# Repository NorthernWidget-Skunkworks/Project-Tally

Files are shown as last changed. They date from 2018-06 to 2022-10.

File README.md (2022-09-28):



# Project-Tally
A minimal ultra low power digital event counter, designed to be a counterpart to a traditional data logger to measure and average rapid events like an anemometer reading

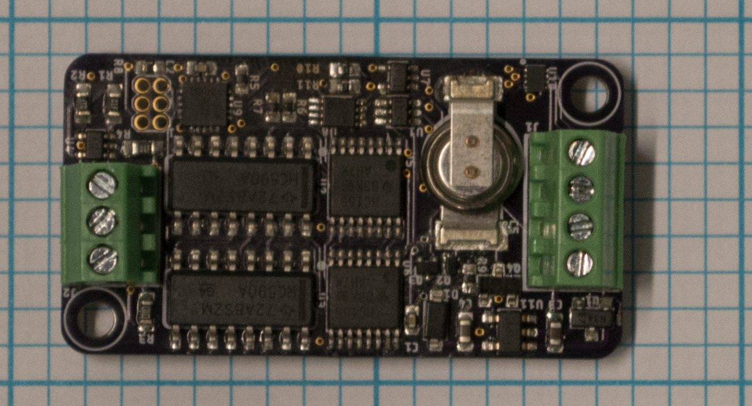
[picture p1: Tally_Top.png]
TallyBoardImage


## Features:
- On board super capacitor (can be self powered between readings/recharge) 
- Extreme low power 
- 3.3/5v capable 
- I2C interface
- Measure up to 65536 (2^16) events before rollover
- Integrated input pullup/pulldown
- Integrated input conditioning (allows for non-binary inputs)

Using jumpers on bottom side of board, can configure input as pullup, pulldown (ultra low power mode), or direct input if driving from another device

### Connectivity:
Device can easily be interfaced to using I2C at either 3.3v or 5v (logic and power). 

A library has been developed for interfacing with Arduino based devices:
[Tally Library](https://github.com/NorthernWidget-Skunkworks/Tally_Library)
### Power Consumption: 

| Mode | Current @ 3.3v | 
| ---- | --- |
| Default | ~4mA |
| Sleep | <100uA |
| Switched | N/A<sup>1</sup> |

<sup>1</sup>When the device is disconnected from the power bus, it draws no external power and runs off the on board super cap. Tested in pull up mode with 100Hz, 50% duty cycle switching input. Ran for 30 minutes, resulting in a consumption of ~ 0.275J of energy = 7.64e-5 Watt Hours -> 15.26 uW avg -> ~ 5uA @ 3v avg. 

#### Maximum input frequency: 

| Mode | Max Freq [kHz] | 
| ---- | --- |
| Pull Up | 16 |
| Pull Down | 10 |
| Direct, Square | 9 |
| Direct, Sine | 22 |
| Direct, Triangle | 22 |

Measured using a function generator with a 2.5v amplitude for push pull tests, and driving an appropriately selected MOSFET for the pull up and pull down variations to act as an analogous switch, once again driven by a function generator. 

---

> ##### ***"Errors using inadequate data are much less than those using no data at all."***
> - **[Charles Babbage](https://en.wikipedia.org/wiki/Charles_Babbage)**

**Concept and design by [Bobby Schulz](https://github.com/bschulz1701) at Northern Widget**

<br>
<br />This work is licensed under a <a rel="license" href="http://creativecommons.org/licenses/by-sa/4.0/">Creative Commons Attribution-ShareAlike 4.0 International License</a>.

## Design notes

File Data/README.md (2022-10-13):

# Wind tunnel test and best fit

`velocity = 0.905 * rps + 0.468`

*Clearly, this breaks down at very slow wind speeds*

`R^2 = 0.959`

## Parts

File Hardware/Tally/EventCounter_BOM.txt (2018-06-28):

Partlist exported from C:/Users/You/Documents/Project-Tally/EventCounter.sch at 6/28/2018 11:52 AM

Qty Value                      Device                     Package                    Parts          Description                                                                                                     DIGIKEY             DISP    MF                  MPN                PROD_ID     VALUE   VALUE_PART
1                              CONN_02SCREW_2.54          1X02_2.54_SCREWTERM        J2             Multi connection point. Often used as Generic Header-pin footprint for 0.1 inch spaced/style header connections ED10561-ND                  OnShore             OSTVN02A150                                      
2                              MOUNTING_HOLE2_NP          2_56                       H1, H2         Genaric Mechanical Mounting Hole                                                                                                                                                                                 
2                              SN74HC165D                 SO16                       U5, U6         SN74HC165 - 8 bit PISO shift register                                                                           296-8250-1-ND               TI                  SN74HC165DR                                      
2                              SN74HC590AD                SO16                       U3, U4         SN74HC590A - 8 bit binary counter with direct clear                                                             296-8340-5-ND               TI                  SN74HC590AD                                      
3                              SN74LVC1G14DCK             DCK_R-PDSO-G5              U1, U9, U10    SN74x1G14 - Single Schmitt Triger Inverter                                                                      296-11608-1-ND              TI                  SN74LVC1G14DCKR                                  
1   0.1uF                      C-EU0.1UFC0603             C0603                      C2             CAPACITOR, European symbol                                                                                      490-6051-1-ND               Murata              GCM188R71E104KA57D                               
4   10M                        R-EU_10MR0603              R0603                      R3, R5, R6, R8 RESISTOR, European symbol                                                                                       RMCF0603FT10M0CT-ND         Stackpole           RMCF0603FT10M0                         10M       
1   10k                        R-EU_10KR0603              R0603                      R1             RESISTOR, European symbol                                                                                       P10.0KHCT-ND                Panasonic           ERJ-3EKF1002V                          10k       
2   1uF                        C-EU1UFC0603               C0603                      C1, C3         CAPACITOR, European symbol                                                                                      1276-6524-1-ND              Samsung             1276-6524-1-ND                                   
1   2N7002                     MOSFET-NCH-2N7002PW        SOT323                     Q1             N-channel MOSFETs                                                                                               2N7002W-FDICT-ND            Diodes Incorporated 2N7002W-7-F        TRANS-11151 2N7002            
3   3.3M                       R-EU_3.3MR0603             R0603                      R2, R4, R7     RESISTOR, European symbol                                                                                       RMCF0603FT3M30CT-ND         Stackpole           RMCF0603FT3M30                         3.3M      
1   CONN_42.54_SCREW           CONN_42.54_SCREW           1X04_SCREW                 J1             Genaric 4 pin connector                                                                                         ED10563-ND                  On Shore            OSTVN04A150                                      
1   DMG3404                    MOSFET-NCH-DMG3404L        SOT23-3                    Q3             N-channel MOSFETs                                                                                               DMG3404L-7DICT-ND           Diodes Incorporated DMG3404L-7                     DMG3404           
1   JUMPER-SMT_2_NC_PASTE_SILK JUMPER-SMT_2_NC_PASTE_SILK SMT-JUMPER_2_NC_PASTE_SILK JP1            Normally closed solder jumper                                                                                                                                                                                    
3   MCP6041                    MCP6041                    SOT23-5                    U2, U7, U8     MCP6041 - Low Power Rail to Rail Op-Amp                                                                         MCP6041T-I/OTCT-ND  MCP6041 Microchip           MCP6041T-I/OT                                    
1   MIC842H                    MIC842H                    DCK_R-PDSO-G5              U$1            Comparator with internal voltage referance (1.24V), 5V and 3.3V compatable, 20mA output current                 576-2926-1-ND               Microchip           MIC842HYC5-TR

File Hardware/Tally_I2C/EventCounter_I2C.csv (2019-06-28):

Qty | Value | Device | Package | Parts | Description | DIGIKEY | MF | MOUSER | MPN | VALUE | VALUE_PART
1 |  | DIODESOD-123 | SOD-123 | D1 | Genaric Diode | BAT43W-FDICT-ND | Diodes Incorporated |  | BAT43W-7-F
2 |  | MOUNTING_HOLE2_NP | 2_56 | H1, H2 | Genaric Mechanical Mounting Hole
1 |  | SN74AUP2G14SC70 | DCK_R-PDSO-G6 | U1 | SN74x2G14 - Dual Schmitt Triger Inverter | 296-27361-1-ND | TI |  | SN74AUP2G14DCKR
2 |  | SN74HC165PW | TSSOP16 | U5, U6 | SN74HC165 - 8 bit PISO shift register | 296-8253-1-ND | TI |  | SN74HC165PWR
2 |  | SN74HC590AD | SO16 | U2, U3 | SN74HC590A - 8 bit binary counter with direct clear | 296-8340-5-ND | TI |  | SN74HC590AD
2 | 0.1uF | C-EU0.1UFC0402 | C0402 | C1, C2 | CAPACITOR, European symbol | 490-4759-1-ND | Murata |  | GCM155R71C104KA55D
1 | 100k | R-EU_100KR0603 | R0603 | R3 | RESISTOR, European symbol | RC0402FR-071ML | Yageo |  | RC0603FR-07100KL |  | 100k
3 | 10M | R-EU_10MR0603 | R0603 | R1, R2, R4 | RESISTOR, European symbol | RMCF0603FT10M0CT-ND | Stackpole |  | RMCF0603FT10M0 |  | 10M
5 | 10k | R-EU_10KR0402 | R0402 | R5, R6, R7, R8, R11 | RESISTOR, European symbol | 311-10KJRCT-ND | Yageo |  | RC0402JR-0710KL |  | 10k
2 | 1M | R-EU_1MR0402 | R0402 | R9, R10 | RESISTOR, European symbol | 311-1.00MLRCT-ND | Yageo |  | RC0402FR-071ML |  | 1M
2 | 1uF | C-EU1UFC0603 | C0603 | C3, C4 | CAPACITOR, European symbol | 490-10479-1-ND | Murata |  | GRM188R61C105KA12D
1 | 220mF | CPOL-EUHL | HL | C5 | POLARIZED CAPACITOR, European symbol | 604-1020-1-ND | Elna |  | DSK-3R3H224U-HL
1 | ATTINY441/841VQFN | ATTINY441/841VQFN | VQFN-20 | U9 | ATtiny841/441 8 bit AVR Microcontroller | ATTINY841-MMHRCT-ND | Atmel |  | ATTINY841-MMHR
1 | AVRISP1.27MM | AVRISP1.27MM | 2X3_1.27 | ISP1 | AVR ISP HEADER
1 | CONN_32.54_SCREW | CONN_32.54_SCREW | 1X03_SCREW | J2 | Genaric 3 terminal header | ED10562-ND | On Shore |  | OSTVN03A150
1 | CONN_42.54_SCREW | CONN_42.54_SCREW | 1X04_SCREW | J1 | Genaric 4 terminal header | ED10563-ND | On Shore |  | OSTVN04A150
1 | DMG3404 | MOSFET-NCH-DMG3404L | SOT23-3 | Q1 | N-channel MOSFETs | DMG3404L-7DICT-ND | Diodes Incorporated |  | DMG3404L-7 | DMG3404
1 | JUMPER-SMT_3_1-NC_PASTE_SILK | JUMPER-SMT_3_1-NC_PASTE_SILK | SMT-JUMPER_3_1-NC_PASTE_SILK | JP0 | Normally closed solder jumper (1 of 2 connections)
1 | MOSFET-NCH-RE1C002UN | MOSFET-NCH-RE1C002UN | SC-89 | Q3 | N-channel MOSFETs | RE1C002UNTCLCT-ND | Rohm |  | RE1C002UNTCL
1 | MOSFET_PCH-NX2301P | MOSFET_PCH-NX2301P | SOT23-3 | Q4 | P-channel MOSFETs | 1727-1148-1-ND | Nexperia |  | NX2301P | 215
1 | MOSFET_PCH-RZM001P02 | MOSFET_PCH-RZM001P02 | SOT723 | Q2 | P-channel MOSFETs | RZM001P02T2LCT-ND | Rohm |  | RZM001P02T2L
1 | SN74AUP1G34SC70 | SN74AUP1G34SC70 | DCK_R-PDSO-G5 | U7 | SN74AUP1G34 - Logic Buffer | 296-17230-1-ND | TI |  | SN74LVC1G34DCKR
1 | SN74AUP3G34DCU | SN74AUP3G34DCU | DCU_(R-PDSO-G8) | U8 | SN74AUP3G34 - Logic Buffer | 296-25595-1-ND | TI |  | SN74AUP3G34DCUR
1 | TLV3691DCK | TLV3691DCK | DCK_R-PDSO-G5 | U4 | TLV3691 - Nanopower Analog Comparator | 296-37910-1-ND | TI |  | TLV3691IDCKR
1 | TPS7A0533DBV | TPS7A0533DBV | SOT23-5 | U11 | TPS7A05* - Ultra Low Power Low Dropout Linear Regulator | 296-50256-1-ND | TI | 595-TPS7A0533PDBVR | TPS7A0533PDBVR
1 | TXS0102DQM | TXS0102DQM | DQM_R-PX2SON-N8 | U10 | TXS0102 - 2 Channel Bidirectional Voltage Level Translator | 296-28435-1-ND | TI |  | TXS0102DQMR

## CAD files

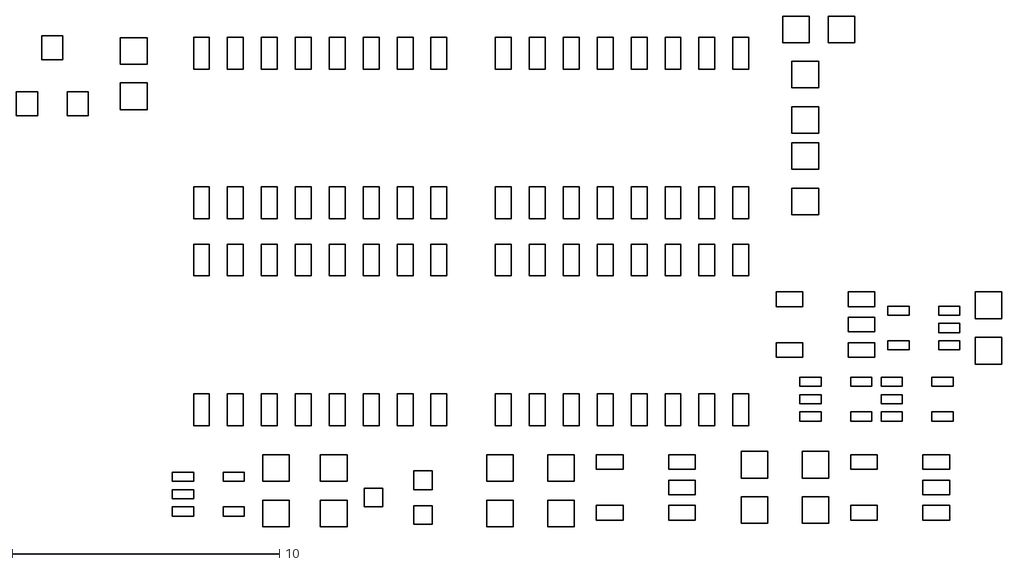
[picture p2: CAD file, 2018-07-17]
Hardware/Tally/Stencil.dxf
36.9 x 19.1

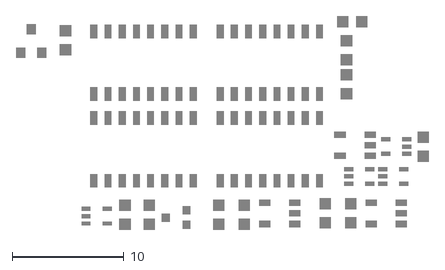
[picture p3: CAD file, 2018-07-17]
Hardware/Tally/EventCounter.dxf
36.9 x 19.1

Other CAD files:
3Dprint/StencilMount_Tally_I2C.SLDPRT
Hardware/Tally/EventCounter-bcream.dxf
Hardware/Tally/EventCounter-tcream.dxf
3Dprint/StencilMount_Tally_I2C.STL

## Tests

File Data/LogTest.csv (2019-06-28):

Freq, Measured (Max) [Hz] | Freq, Measured (Min) [Hz] | Freq, Measured (Avg) [Hz] | Freq, Tally [Hz]
1.659 | 1.456 | 1.549 | 1.55
4.114 | 3.723 | 3.906 | 3.9
5.39 | 4.994 | 5.236 | 5.233
0.822 | 0.639 | 0.721 | 0.7166

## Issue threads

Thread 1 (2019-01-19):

Fix orientation on switched power adapter

bschulz1701, 2019-01-19:
Fix orientation of pins so they line up with Tally correctly

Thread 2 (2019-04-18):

Digital Pull-up/down resistors

bschulz1701, 2019-04-18:
### Upgrade (Only relevant on I2C version)
Make the pull up/pull down resistors on the pulse input be able to be controlled via the micro over I2C

### Implementation
Use a mosfet to connect or disconnect the appropriate resistor, use a digital latch in order to drive the gate of the mosfet so that the fet will remain in the set position even when the micro is powered down. May also need to add a buffer in series with latch in order to prevent reverse current in shutdown mode?

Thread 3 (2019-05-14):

Add Jumper for Capacitor

bschulz1701, 2019-05-14:
Potentially add a jumper to disconnect the capacitor when not used (by an always on system) in order to reduce current spikes (due to charging) and to simplify power analysis

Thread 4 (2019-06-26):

Add mount points for Grove connector

bschulz1701, 2019-06-26:
Add connection pads for Grove connector underneath the I2C screw terminal

Consider adding Qwiic connection as well depending on size and ease of addition

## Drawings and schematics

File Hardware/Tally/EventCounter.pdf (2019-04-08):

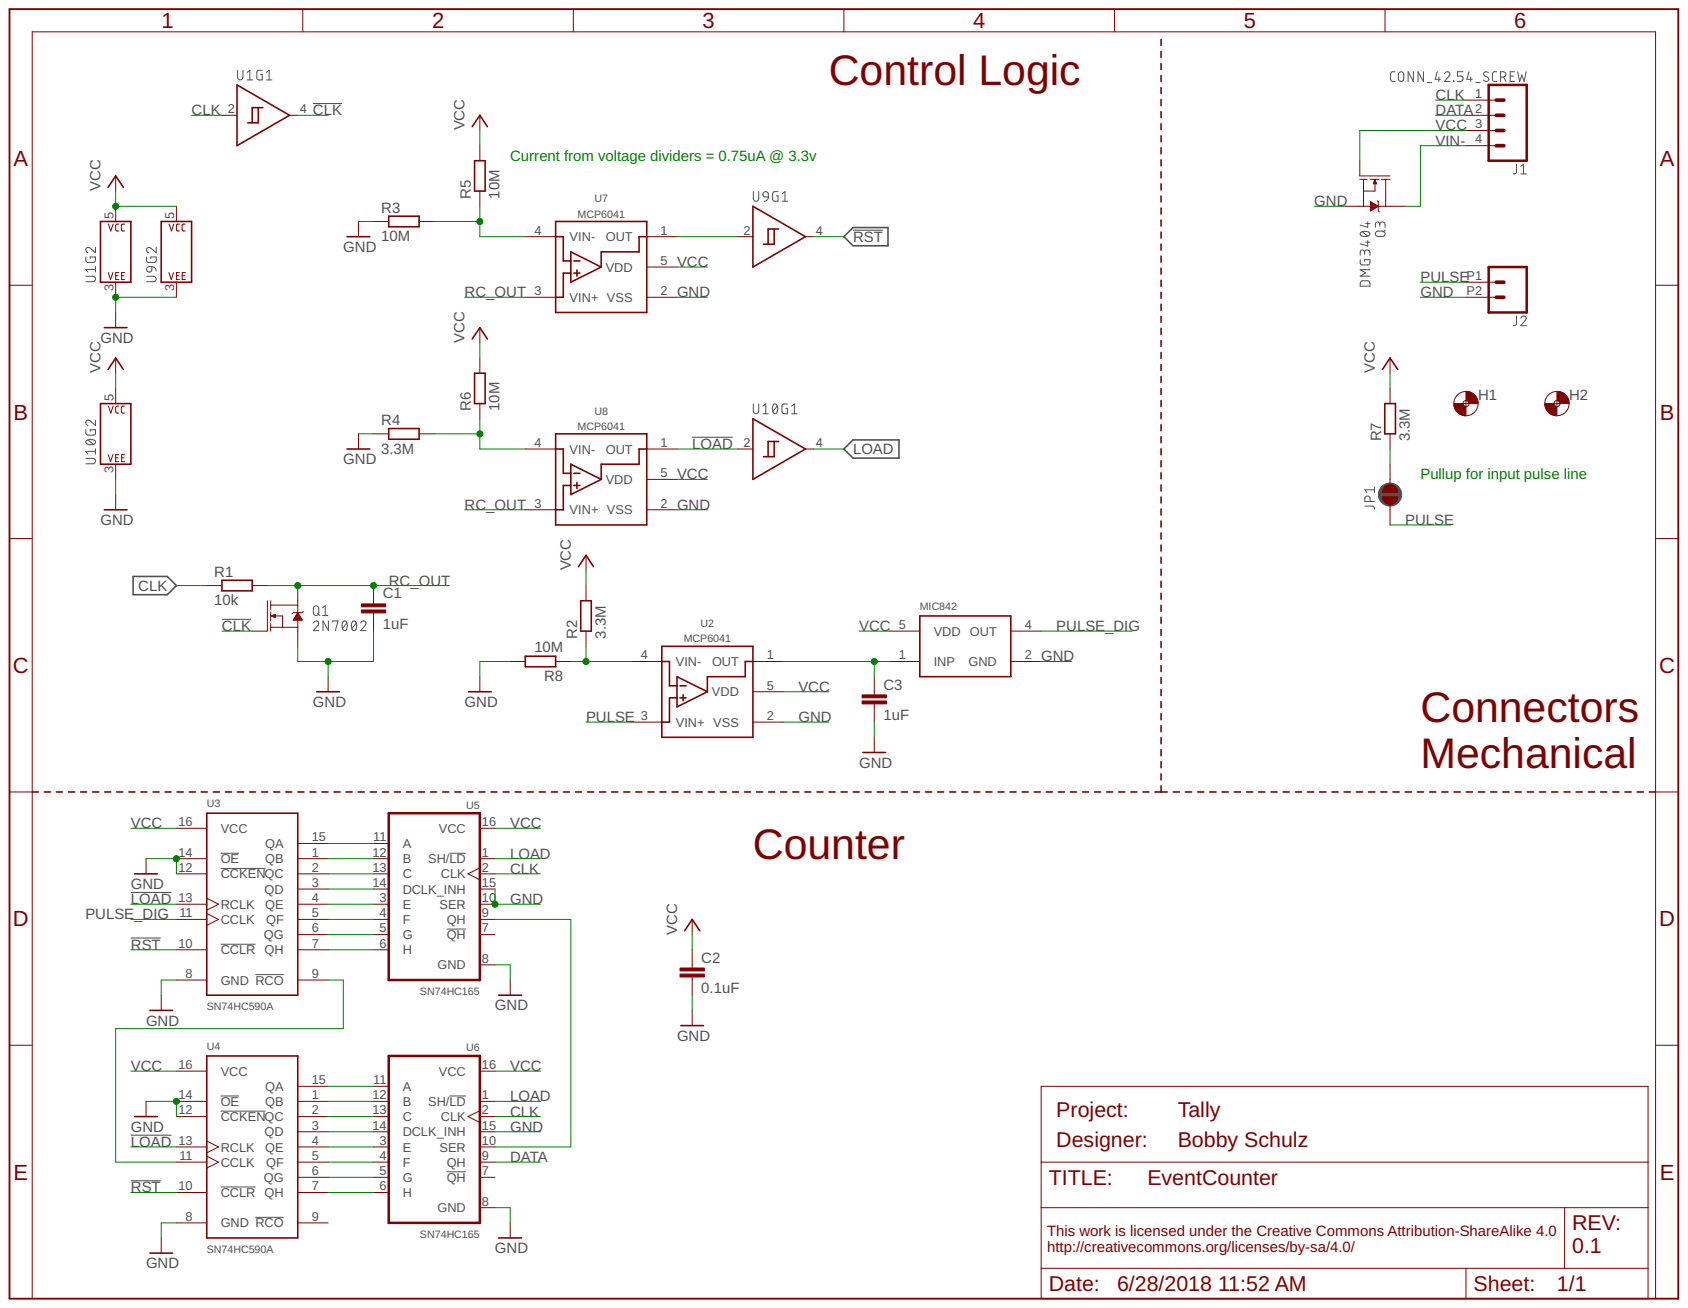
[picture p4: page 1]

Current from voltage dividers = 0.75uA @ 3.3v

Pullup for input pulse line

This work is licensed under the Creative Commons Attribution-ShareAlike 4.0 http://creativecommons.org/licenses/by-sa/4.0/ | REV: 0.1

Date: 6/28/2018 11:52 AM | Sheet: 1/1

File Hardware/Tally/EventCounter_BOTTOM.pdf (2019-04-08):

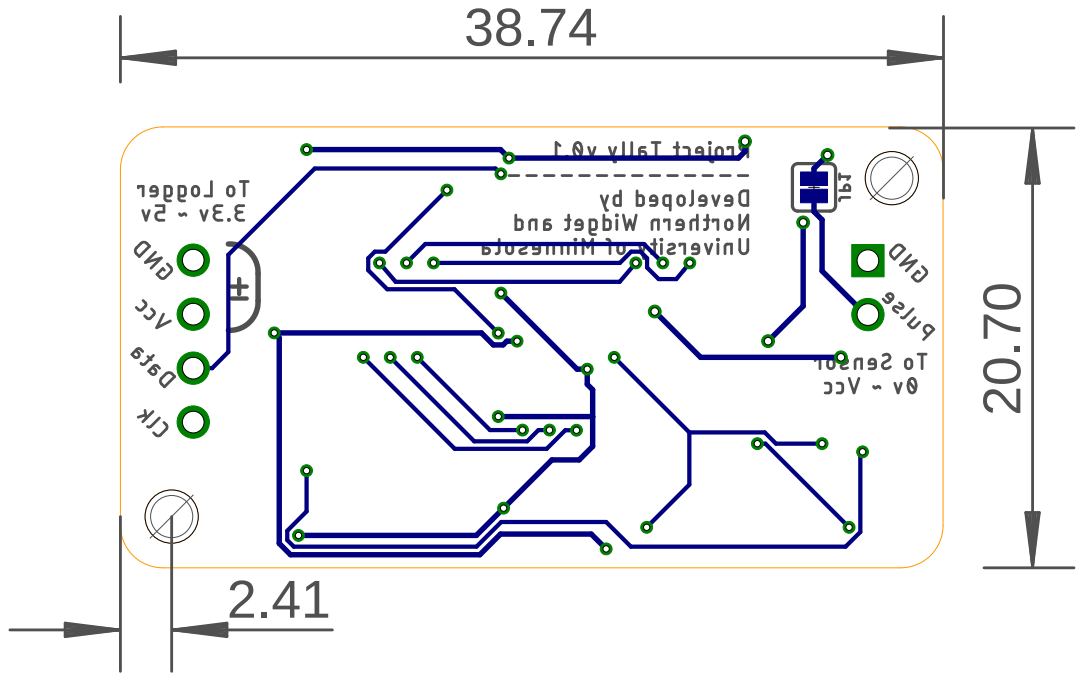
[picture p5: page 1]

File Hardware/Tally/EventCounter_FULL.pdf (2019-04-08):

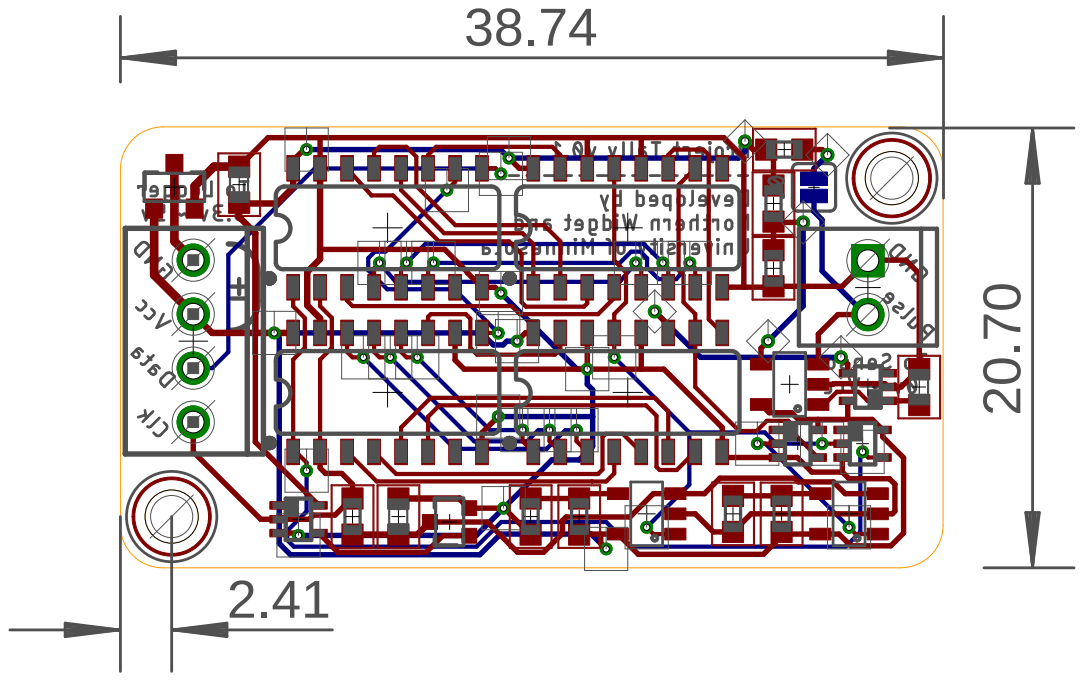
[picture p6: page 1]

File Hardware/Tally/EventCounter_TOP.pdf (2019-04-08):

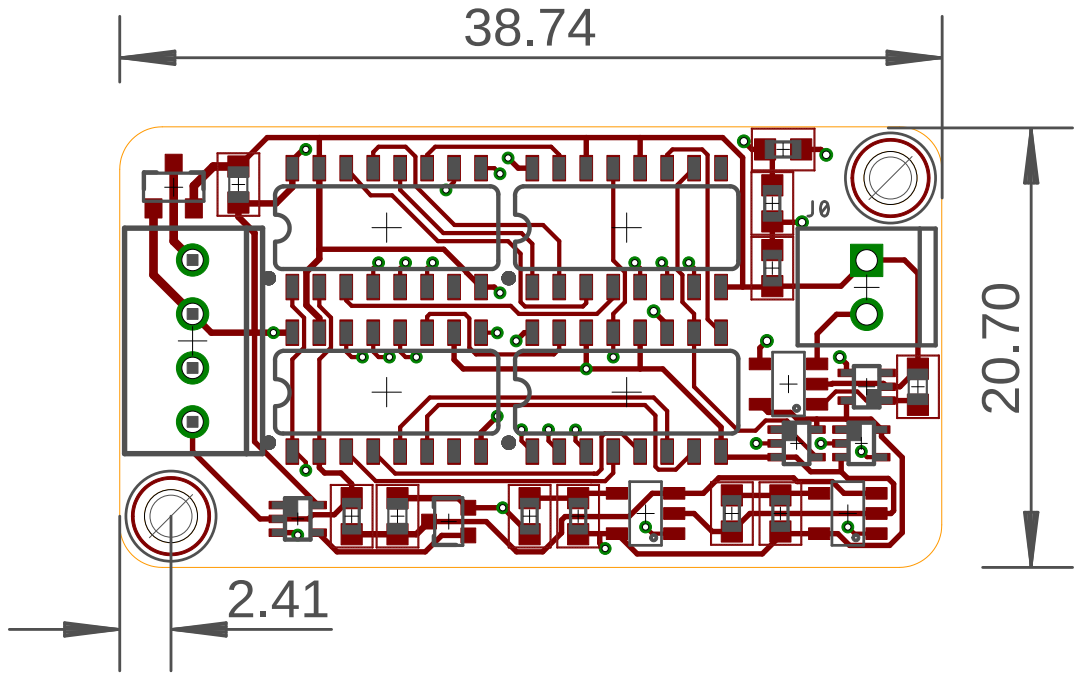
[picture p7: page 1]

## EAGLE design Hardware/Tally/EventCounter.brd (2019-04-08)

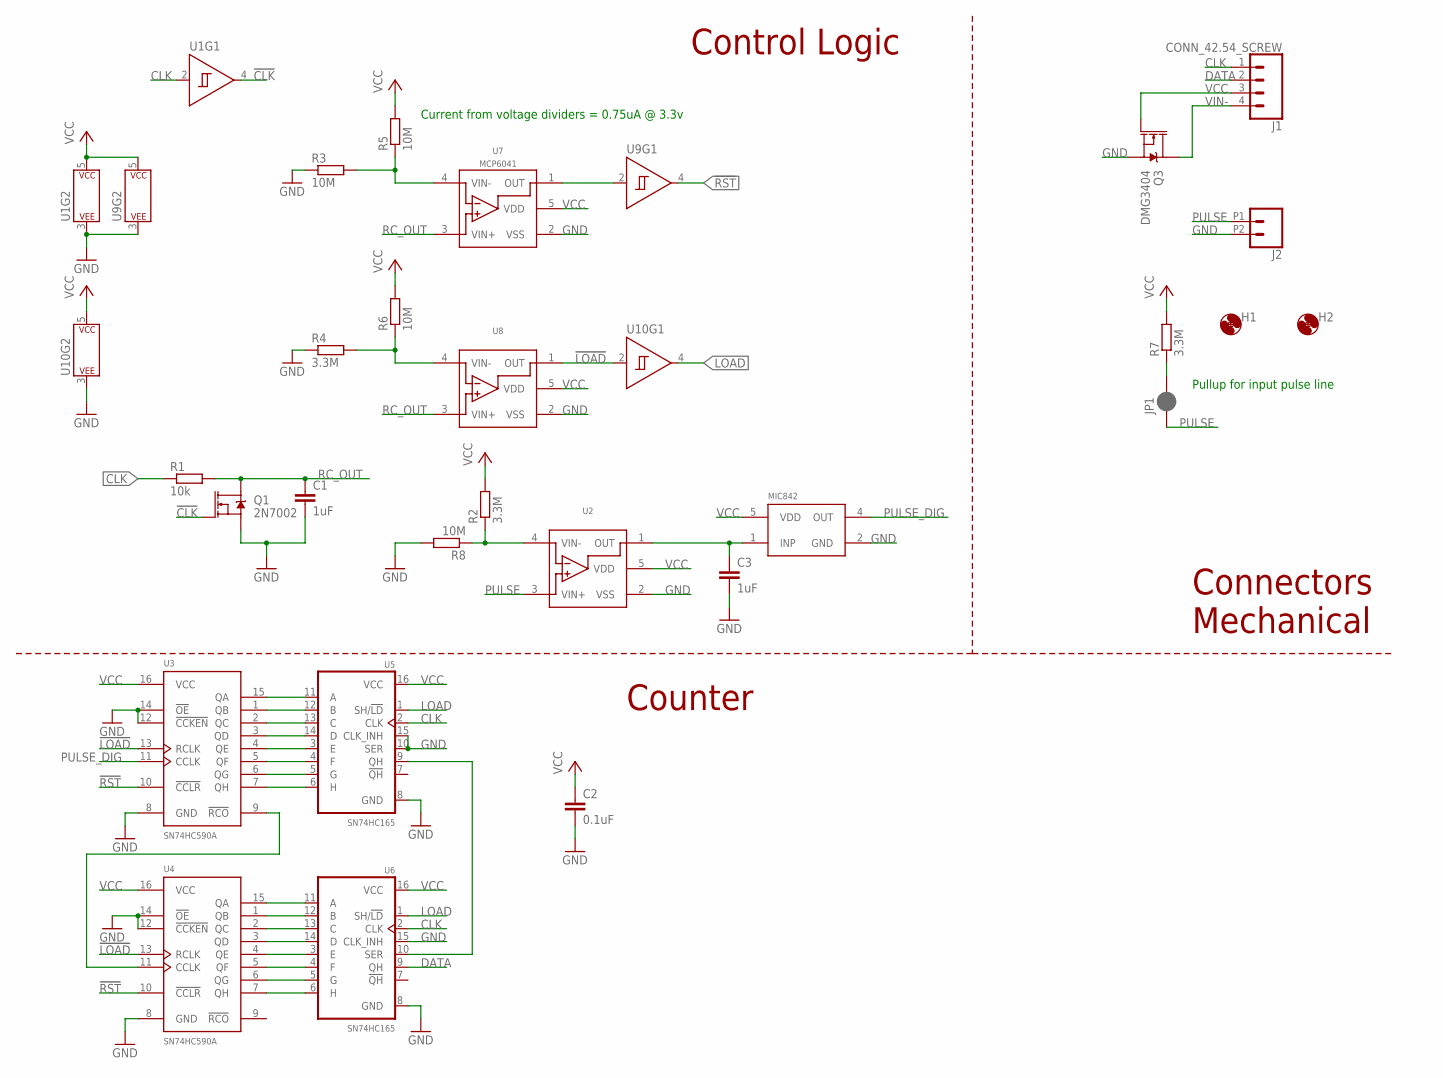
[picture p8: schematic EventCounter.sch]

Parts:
C1, C3: 1uF; C0603
C2: 0.1uF; C0603
H1, H2: MOUNTING_HOLE2_NP; 2_56
J1: CONN_42.54_SCREW; 1X04_SCREW
J2: CONN_02SCREW_2.54; 1X02_2.54_SCREWTERM
JP1: JUMPER-SMT_2_NC_PASTE_SILK; SMT-JUMPER_2_NC_PASTE_SILK
Q1: 2N7002; SOT323
Q3: DMG3404; SOT23-3
R1: 10k; R0603
R2, R4, R7: 3.3M; R0603
R3, R5, R6, R8: 10M; R0603
U1, U9, U10: SN74LVC1G14DCK; DCK_R-PDSO-G5
U2, U7, U8: MCP6041; SOT23-5
U3, U4: SN74HC590AD; SO16
U5, U6: SN74HC165D; SO16
U$1: MIC842H; DCK_R-PDSO-G5

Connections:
!CLK: Q1.1 (G), U1.4 (Y)
!LOAD: U3.13 (RCLK), U4.13 (RCLK), U8.1 (OUT), U10.2 (A)
!RST: U3.10 (!CCLR), U4.10 (!CCLR), U9.4 (Y)
CLK: J1.1, R1.1, U1.2 (A), U5.2 (CLK), U6.2 (CLK)
DATA: J1.2, U6.9 (QH)
GND: C1.2, C2.2, C3.2, J2.P2 (2), Q1.2 (S), Q3.2 (S), R3.1, R4.1, R8.2, U1.3 (P$V-), U2.2 (VSS), U3.8 (GND), U3.12 (!CCKEN), U3.14 (!OE), U4.8 (GND), U4.12 (!CCKEN), U4.14 (!OE), U5.8 (GND), U5.10 (SER), U5.15 (CLK_INH), U6.8 (GND), U6.15 (CLK_INH), U7.2 (VSS), U8.2 (VSS), U9.3 (P$V-), U10.3 (P$V-), U$1.2 (GND)
LOAD: U5.1 (SH/!LD), U6.1 (SH/!LD), U10.4 (Y)
unnamed: U4.15 (QA), U6.11 (A)
unnamed: U4.1 (QB), U6.12 (B)
unnamed: U4.2 (QC), U6.13 (C)
unnamed: U4.3 (QD), U6.14 (D)
unnamed: U4.4 (QE), U6.3 (E)
unnamed: U4.5 (QF), U6.4 (F)
unnamed: U4.6 (QG), U6.5 (G)
unnamed: U4.7 (QH), U6.6 (H)
unnamed: U3.7 (QH), U5.6 (H)
unnamed: U3.6 (QG), U5.5 (G)
unnamed: U3.5 (QF), U5.4 (F)
unnamed: U3.4 (QE), U5.3 (E)
unnamed: U3.3 (QD), U5.14 (D)
unnamed: U3.2 (QC), U5.13 (C)
unnamed: U3.1 (QB), U5.12 (B)
unnamed: U3.15 (QA), U5.11 (A)
unnamed: U5.9 (QH), U6.10 (SER)
unnamed: U3.9 (!RCO), U4.11 (CCLK)
unnamed: R2.1, R8.1, U2.4 (VIN-)
unnamed: JP1.2, R7.1
unnamed: R4.2, R6.1, U8.4 (VIN-)
unnamed: C3.1, U2.1 (OUT), U$1.1 (INP)
unnamed: R3.2, R5.1, U7.4 (VIN-)
PULSE: J2.P1 (1), JP1.1, U2.3 (VIN+)
PULSE_DIG: U3.11 (CCLK), U$1.4 (OUT)
RC_OUT: C1.1, Q1.3 (D), R1.2, U7.3 (VIN+), U8.3 (VIN+)
RST: U7.1 (OUT), U9.2 (A)
VCC: C2.1, J1.3, Q3.1 (G), R2.2, R5.2, R6.2, R7.2, U1.5 (P$V+), U2.5 (VDD), U3.16 (VCC), U4.16 (VCC), U5.16 (VCC), U6.16 (VCC), U7.5 (VDD), U8.5 (VDD), U9.5 (P$V+), U10.5 (P$V+), U$1.5 (VDD)
VIN-: J1.4, Q3.3 (D)

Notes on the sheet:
Pullup for input pulse line
Counter
Control Logic
Connectors Mechanical
Current from voltage dividers = 0.75uA @ 3.3v

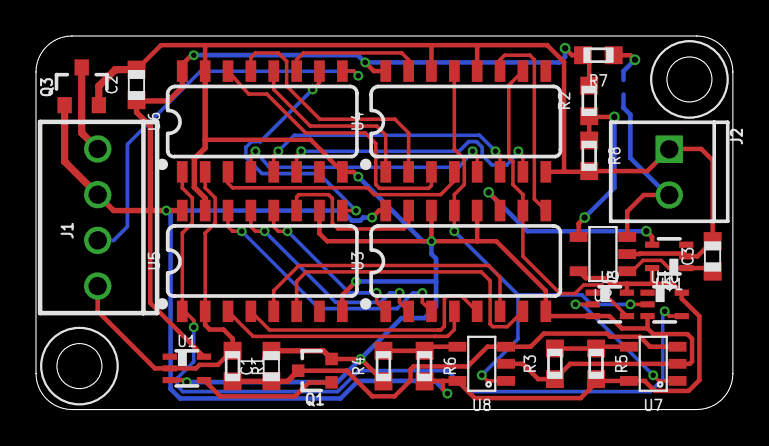
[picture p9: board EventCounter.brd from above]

Board: 2 copper layers, 38.7 x 20.8 mm, 29 parts (1 on the bottom side), 36 nets.

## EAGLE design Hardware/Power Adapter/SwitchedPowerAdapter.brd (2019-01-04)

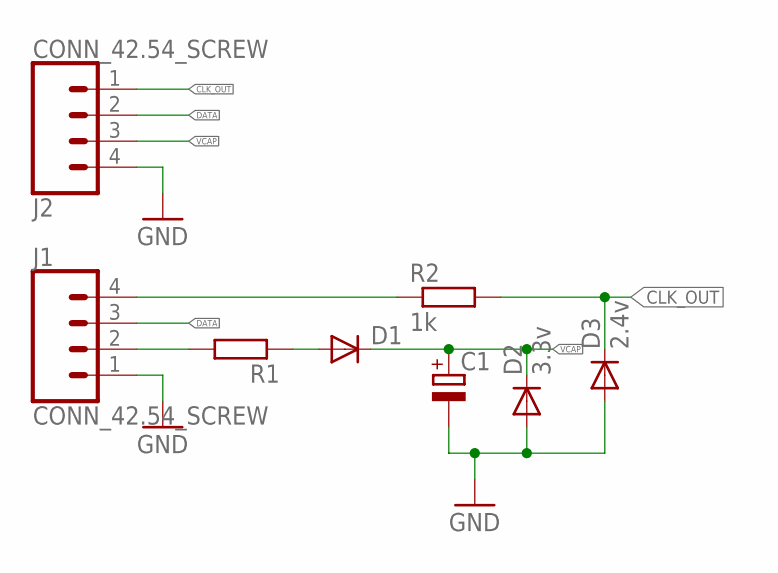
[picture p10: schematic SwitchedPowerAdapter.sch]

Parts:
C1: CPOL-EUHL; HL
D1: DIODEDO-214AC; DO214AC; MPN S1A; DIGIKEY S1AFSCT-ND
D2: 3.3v; SOD-123; MPN MMSZ4683-HE3-08; DIGIKEY MMSZ4683-HE3-08GICT-ND
D3: 2.4v; SOD-123
J1, J2: CONN_42.54_SCREW; 1X04_SCREW
R1: R-EU_R2512; R2512
R2: 1k; R0402

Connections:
CLK: J1.4, R2.1
CLK_OUT: D3.CAT (C), J2.1, R2.2
DATA: J1.3, J2.2
GND: C1.-, D2.ANODE (A), D3.ANODE (A), J1.1, J2.4
unnamed: J1.2, R1.2
unnamed: D1.A, R1.1
VCAP: C1.+, D1.C, D2.CAT (C), J2.3

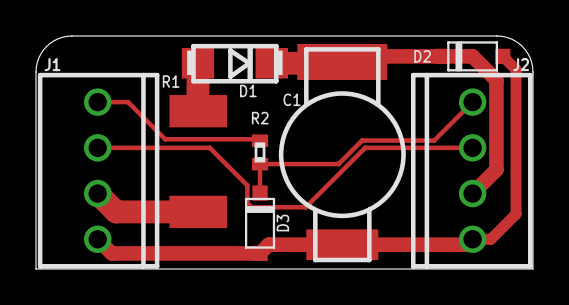
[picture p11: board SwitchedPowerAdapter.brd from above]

Board: 2 copper layers, 27.6 x 12.9 mm, 8 parts (0 on the bottom side), 7 nets.

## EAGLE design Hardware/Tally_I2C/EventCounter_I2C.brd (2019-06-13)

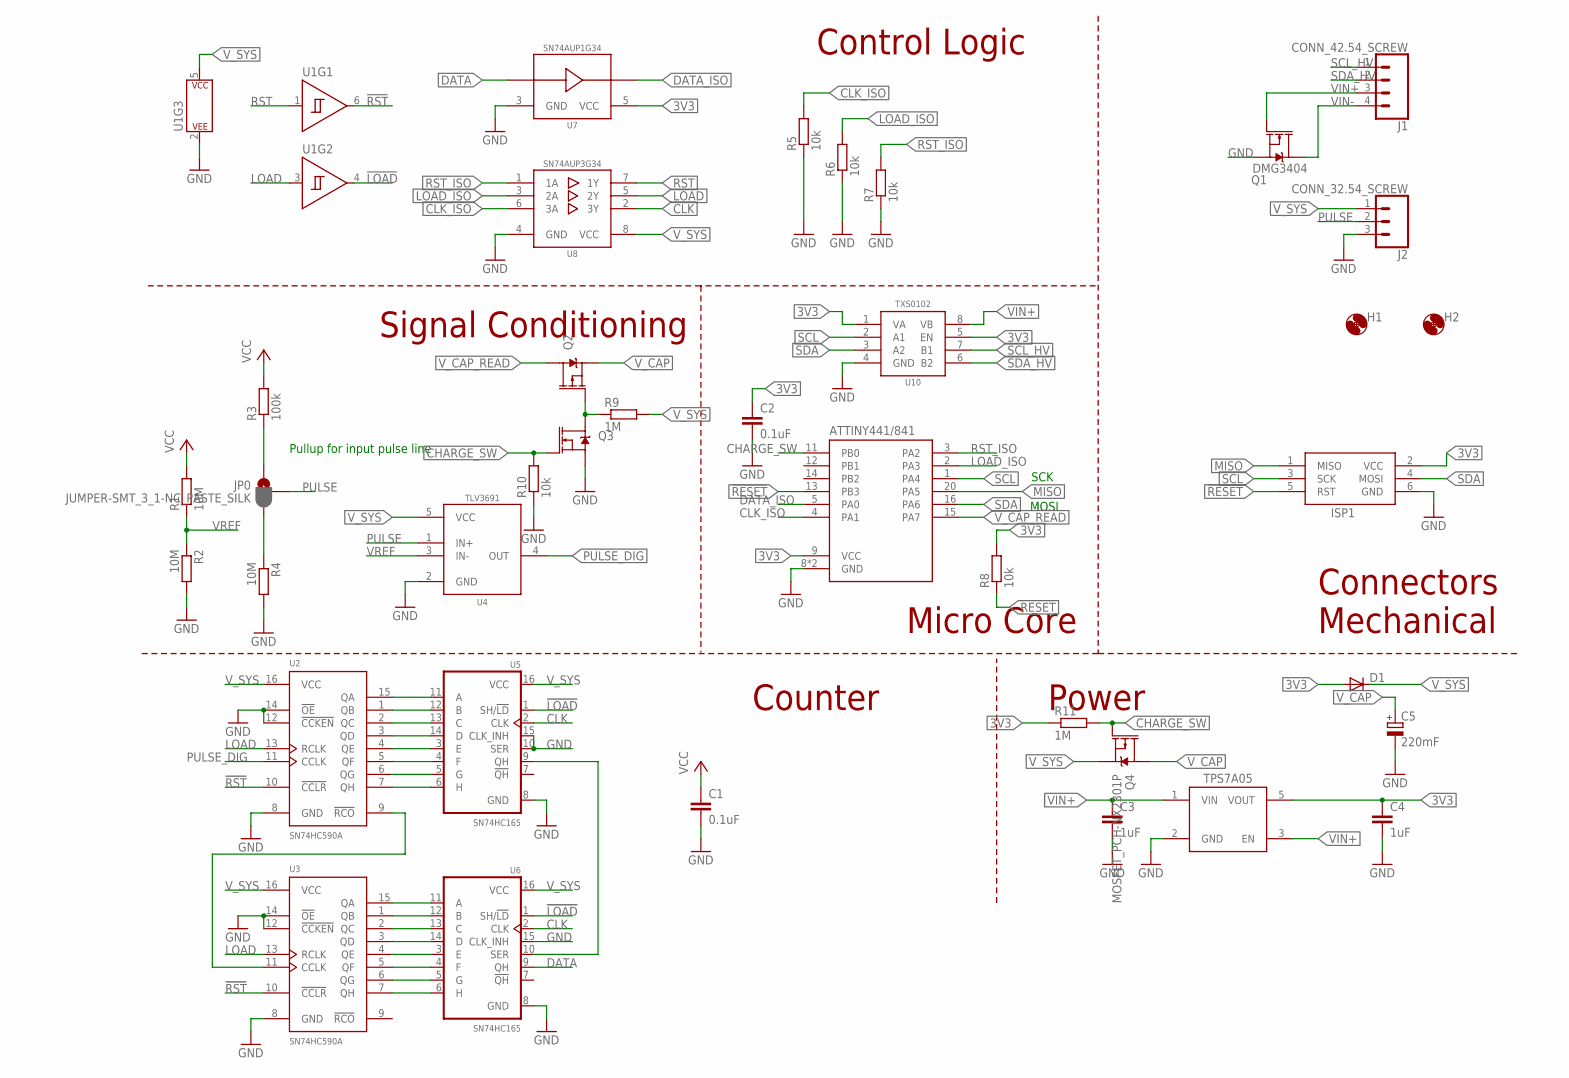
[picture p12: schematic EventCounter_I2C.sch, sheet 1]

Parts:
C1, C2: 0.1uF; C0402
C3, C4: 1uF; C0603
C5: 220mF; HL; MPN DSK-3R3H224U-HL; DIGIKEY 604-1020-1-ND
D1: DIODESOD-123; SOD-123; MPN BAT43W-7-F; DIGIKEY BAT43W-FDICT-ND
H1, H2: MOUNTING_HOLE2_NP; 2_56
ISP1: AVRISP1.27MM; 2X3_1.27
J1: CONN_42.54_SCREW; 1X04_SCREW
J2: CONN_32.54_SCREW; 1X03_SCREW
JP0: JUMPER-SMT_3_1-NC_PASTE_SILK; SMT-JUMPER_3_1-NC_PASTE_SILK
Q1: DMG3404; SOT23-3
Q2: MOSFET_PCH-RZM001P02; SOT723
Q3: MOSFET-NCH-RE1C002UN; SC-89
Q4: MOSFET_PCH-NX2301P; SOT23-3
R1, R2, R4: 10M; R0603
R3: 100k; R0603
R5, R6, R7, R8, R10: 10k; R0402
R9, R11: 1M; R0402
U1: SN74AUP2G14SC70; DCK_R-PDSO-G6
U2, U3: SN74HC590AD; SO16
U4: TLV3691DCK; DCK_R-PDSO-G5
U5, U6: SN74HC165PW; TSSOP16
U7: SN74AUP1G34SC70; DCK_R-PDSO-G5
U8: SN74AUP3G34DCU; DCU_(R-PDSO-G8)
U9: ATTINY441/841VQFN; VQFN-20
U10: TXS0102DQM; DQM_R-PX2SON-N8
U11: TPS7A0533DBV; SOT23-5

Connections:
3V3: C2.1, C4.1, D1.ANODE (A), ISP1.2 (VCC), R8.2, R11.1, U7.5 (VCC), U9.9 (VCC), U10.1 (VA), U10.5 (EN), U11.5 (VOUT)
!LOAD: U1.4 (Y), U5.1 (SH/!LD), U6.1 (SH/!LD)
!RESET: ISP1.5 (RST), R8.1, U9.13 (PB3)
!RST: U1.6 (Y), U2.10 (!CCLR), U3.10 (!CCLR)
CHARGE_SW: Q3.1 (G), Q4.1 (G), R10.2, R11.2, U9.11 (PB0)
CLK: U5.2 (CLK), U6.2 (CLK), U8.2 (3Y)
CLK_ISO: R5.2, U8.6 (3A), U9.4 (PA1)
DATA: U6.9 (QH), U7.2 (A)
DATA_ISO: U7.4 (Y), U9.5 (PA0)
GND: C1.2, C2.2, C3.2, C4.2, C5.-, ISP1.6 (GND), J2.3, Q1.2 (S), Q3.2 (S), R2.2, R4.2, R5.1, R6.1, R7.1, R10.1, U1.2 (P$V-), U2.8 (GND), U2.12 (!CCKEN), U2.14 (!OE), U3.8 (GND), U3.12 (!CCKEN), U3.14 (!OE), U4.2 (GND), U5.8 (GND), U5.10 (SER), U5.15 (CLK_INH), U6.8 (GND), U6.15 (CLK_INH), U7.3 (GND), U8.4 (GND), U9.8 (GND), U9.EP (GND), U10.4 (GND), U11.2 (GND)
LOAD: U1.3 (A), U2.13 (RCLK), U3.13 (RCLK), U8.5 (2Y)
LOAD_ISO: R6.2, U8.3 (2A), U9.2 (PA3)
MISO: ISP1.1 (MISO), U9.20 (PA5)
unnamed: U3.15 (QA), U6.11 (A)
unnamed: U3.1 (QB), U6.12 (B)
unnamed: U3.2 (QC), U6.13 (C)
unnamed: U3.3 (QD), U6.14 (D)
unnamed: U3.4 (QE), U6.3 (E)
unnamed: U3.5 (QF), U6.4 (F)
unnamed: U3.6 (QG), U6.5 (G)
unnamed: U3.7 (QH), U6.6 (H)
unnamed: U2.7 (QH), U5.6 (H)
unnamed: U2.6 (QG), U5.5 (G)
unnamed: U2.5 (QF), U5.4 (F)
unnamed: U2.4 (QE), U5.3 (E)
unnamed: U2.3 (QD), U5.14 (D)
unnamed: U2.2 (QC), U5.13 (C)
unnamed: U2.1 (QB), U5.12 (B)
unnamed: U2.15 (QA), U5.11 (A)
unnamed: U5.9 (QH), U6.10 (SER)
unnamed: U2.9 (!RCO), U3.11 (CCLK)
unnamed: JP0.3, R4.1
unnamed: JP0.1, R3.1
unnamed: Q2.1 (G), Q3.3 (D), R9.1
PULSE: J2.2, JP0.2, U4.1 (IN+)
PULSE_DIG: U2.11 (CCLK), U4.4 (OUT)
RST: U1.1 (A), U8.7 (1Y)
RST_ISO: R7.2, U8.1 (1A), U9.3 (PA2)
SCL: ISP1.3 (SCK), U9.1 (PA4), U10.2 (A1)
SCL_HV: J1.1, U10.7 (B1)
SDA: ISP1.4 (MOSI), U9.16 (PA6), U10.3 (A2)
SDA_HV: J1.2, U10.6 (B2)
VIN+: C3.1, J1.3, Q1.1 (G), U10.8 (VB), U11.1 (VIN), U11.3 (EN)
VIN-: J1.4, Q1.3 (D)
VREF: R1.1, R2.1, U4.3 (IN-)
V_CAP: C5.+, Q2.2 (S), Q4.3 (D)
V_CAP_READ: Q2.3 (D), U9.15 (PA7)
V_SYS: C1.1, D1.CAT (C), J2.1, Q4.2 (S), R1.2, R3.2, R9.2, U1.5 (P$V+), U2.16 (VCC), U3.16 (VCC), U4.5 (VCC), U5.16 (VCC), U6.16 (VCC), U8.8 (VCC)

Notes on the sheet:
Pullup for input pulse line
Counter
Control Logic
Connectors Mechanical
MOSI
SCK
Power
Micro Core
Signal Conditioning

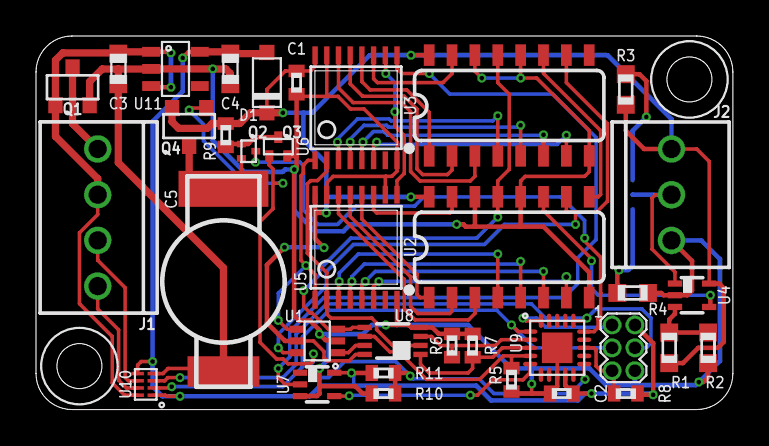
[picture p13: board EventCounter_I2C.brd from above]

Board: 2 copper layers, 38.7 x 20.8 mm, 38 parts (1 on the bottom side), 48 nets.

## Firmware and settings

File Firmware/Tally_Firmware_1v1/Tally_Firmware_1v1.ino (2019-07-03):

/******************************************************************************
Tally_Firmware_1v1.ino
Driver for Tally event counter
Bobby Schulz @ Northern Widget LLC
5/16/2019
https://github.com/NorthernWidget-Skunkworks/Project-Tally

This firmware is to be run on the I2C capable Tally v1.1 in order to allow for interface, control, and data collection 

Firmware Version: 0.2.0

"On two occasions I have been asked, 'Pray, Mr. Babbage, if you put into the machine wrong figures, will the right answers come out?' 
I am not able rightly to apprehend the kind of confusion of ideas that could provoke such a question."
-Charles Babbage

Distributed as-is; no warranty is given.
******************************************************************************/

#include <avr/sleep.h>
#include <avr/power.h>
#include <avr/interrupt.h>
#include "WireS.h"
#define DATA_PIN 10
#define CLK_PIN 9
#define RST_PIN 8
#define LOAD_PIN 7
#define CHARGE_SW 0
#define V_CAP_READ A7

#define CHIP_ID_CALL 0xD0
#define CHIP_ID 0xB0
#define FIRMWARE_NUM 2

uint8_t ADR = 0x33; //DUMMY! FIX! and make changable

// volatile bool GenCall = false; //Flag for generic address call over I2C //FIX! add generalizable address

uint8_t Config = 0; //Global config value
uint8_t Reg[5] = {0}; //Initialize registers
const uint8_t RegLen = sizeof(Reg); //Number of registers in Reg
bool Sample = false; //Flag to get a new sample value
bool Reset = false; //Reset flag
bool Clear = false; //Clear registers
bool Peek = false; //Clear values on read by default
bool Sleep = false; //Do not sleep by default
bool ReadCap = false; //Read float voltage of capacitor 
bool NoCap = false; //Disconnect capacitor, this will be reset on POR

volatile bool StopFlag = false; //Used to indicate a stop condition 
volatile uint8_t RegID = 0; //Used to denote which register will be read from
volatile bool RepeatedStart = false; //Used to show if the start was repeated or not

const unsigned long WAIT_TIME = 100; //Genric wait cycle after read operation, keep device alive for repeated requests

void setup() {
	pinMode(DATA_PIN, INPUT); //Setup GPIO interface pins
	pinMode(CLK_PIN, OUTPUT);
	pinMode(RST_PIN, OUTPUT);
	pinMode(LOAD_PIN, OUTPUT);
	pinMode(CHARGE_SW, OUTPUT);
	ReadVoltage(); //Get voltage on startup, available to read afterwards 
	digitalWrite(CHARGE_SW, LOW); //By default have system charging 

	Wire.begin(ADR);  //Begin slave I2C FIX! Add variable address feature!

	//Setup I2C slave
	Wire.onAddrReceive(AddressEvent); 
	Wire.onRequest(RequestEvent);    
	Wire.onReceive(ReceiveEvent);
	Wire.onStop(StopEvent);
}

void loop() {

	if(Sleep) { //Put device to sleep on wrap arround
		ADCSRA &= ~(1<<ADEN); //Disable ADC
		SPCR   &= ~_BV(SPE); //Disable SPI
		//    PRR = 0xFF;
			set_sleep_mode(SLEEP_MODE_PWR_DOWN);  

		sleep_enable();
		sleep_mode(); //Waits here while in sleep mode

		sleep_disable(); //Wake up
		TWSCRA = bit(TWEN);  //Re-enable I2C
		Wire.begin(ADR);
	}

	int Counter = 0; //Run cycles after wakeup
	while(++Counter < WAIT_TIME) {
		Sample = BitRead(Reg[0], 0);
		Clear = BitRead(Reg[0], 1);
		Reset = BitRead(Reg[0], 2);
		Peek = BitRead(Reg[0], 3);
		Sleep = BitRead(Reg[0], 4); 
		ReadCap = BitRead(Reg[0], 5);
		NoCap = BitRead(Reg[0], 6);

		if(Sample) {
			SplitAndLoad(1, GetTicks()); //Load tick value into register 1
			if(!Peek) ClearTicks(); //Clear counter values if peak is disabled
			Reg[0] = Reg[0] & 0xFE; //Clear sample bit in register
			Sample = false; //Clear sample bit
		}
		if(Reset) { //Software reset of system
			ClearTicks();
			Reg[1] = 0x00; //Clear registers
			Reg[2] = 0x00;
			Reg[0] = Reg[0]; //Reset to POR
			Clear = false; //Clear flag
		}
		if(Clear) {
			ClearTicks(); //Clear registers 
			Reg[0] = Reg[0] & 0xFD; //Clear CLEAR bit
			Reset = false; //Clear flag
		}

		if(ReadCap) {
			ReadVoltage(); //Read voltage and load into I2C regs
			Reg[0] = Reg[0] & 0xDF; //Clear Voltage Read bit
			ReadCap = false; //Clear flag
		}

		if(NoCap) {
			digitalWrite(CHARGE_SW, HIGH); //Disconnect cap from Vin
		}

		if(!NoCap) {
			digitalWrite(CHARGE_SW, LOW); //Connect cap to Vin
		}
		delay(1); //Wait during wake/I2C transaction 
	}
	Counter = 0; //Clear counter to either go to sleep or wrap around
}

void SplitAndLoad(uint8_t Pos, unsigned int Val) //Write 16 bits
{
	uint8_t Len = sizeof(Val);
	for(int i = Pos; i < Pos + Len; i++) {
		Reg[i] = (Val >> (i - Pos)*8) & 0xFF; //Pullout the next byte
	}
}

boolean AddressEvent(uint16_t Address, uint8_t count) //When a valid address is encountered on I2C
{
	// if(Address == 0x00) { //FIX! add generalizable address
	// 	GenCall = true;
	// }
	RepeatedStart = (count > 0 ? true : false);
	return true; // send ACK to master
}

void RequestEvent()  //When I2C values are requested
{	if(RegID == CHIP_ID_CALL) {
		Wire.write(CHIP_ID); //Return Chip ID if requested
		Wire.write(FIRMWARE_NUM); //Send firmware version number
	}
	else {
		for(int i = 0; i < RegLen; i++) {  
			Wire.write(Reg[(RegID + i) % RegLen]);  //Load all bytes (wrap around) into register
		}
	}
}

void ReceiveEvent(int DataLen) //When I2C values are sent 
{
    //Write data to appropriate location
    if(DataLen == 2){
	    //Remove while loop?? 
	    while(Wire.available() < 2); //Only option for writing would be register address, and single 8 bit value
	    uint8_t Pos = Wire.read();
	    uint8_t Val = Wire.read();
	    //Check for validity of write??
	    Reg[Pos] = Val; //Set register value
	}

	// if(DataLen == 1 && GenCall == true) {  //FIX! add generalizable address
	// 	ADR = Wire.read(); //Update address value 
	// }

	// if(DataLen == 1 && GenCall == false){
	// 	RegID = Wire.read(); //Read in the register ID to be used for subsequent read
	// }
	if(DataLen == 1){
		RegID = Wire.read(); //Read in the register ID to be used for subsequent read
	}
}

void StopEvent() //When stop value is detected on I2C
{
	StopFlag = true;
  	RegID = (RegID + Wire.getTransmitBytes()) % RegLen; //Increment register pointer appropriate amount
	//End comunication
}

unsigned int GetTicks() //Read number of ticks from digital logic 
{
	unsigned int Data = 0; //Number of pulses since last read
	digitalWrite(LOAD_PIN, HIGH);  //Pulse LOAD pin low to trigger load of new data
	delayMicroseconds(5); 
  	digitalWrite(LOAD_PIN, LOW); 

  	Data = digitalRead(DATA_PIN);
  	Data = Data << 1; 
	for(int i = 0; i < 15; i++) {
    digitalWrite(CLK_PIN, HIGH); //Clock new data in
		delayMicroseconds(5); //Wait to stabilize
		Data = (Data << 1) | digitalRead(DATA_PIN);
    digitalWrite(CLK_PIN, LOW); 
		delayMicroseconds(5);
	} 
	return Data;
}

void ClearTicks() //Clear digital logic values 
{
	digitalWrite(RST_PIN, HIGH);  //Pulse reset pin high for short interval to trigger reset
	delayMicroseconds(5);
  	digitalWrite(RST_PIN, LOW); 
}

bool ReadVoltage() //Read the bit value at the specified position
{
	digitalWrite(CHARGE_SW, HIGH); //Connect voltage to ADC
	delay(1); //Wait to settle FIX??
	uint16_t Val = analogRead(V_CAP_READ);
	if(!NoCap) digitalWrite(CHARGE_SW, LOW); //Disconnect and continue charging if cap is set to be nominally connected
	Reg[4] = Val >> 8; //Load MSB
	Reg[3] = Val & 0xFF; //Load LSB
}

bool BitRead(uint8_t Val, uint8_t Pos) //Read the bit value at the specified position
{
	return (Val >> Pos) & 0x01;
}

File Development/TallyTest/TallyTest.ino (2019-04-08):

//TallyTest.ino

#define DATA_PIN 11  //Define digital pin connected to data line
#define CLK_PIN 5  //Define digital pin connected to the clock line
#define POWER_PIN 19

//NOTE: Inverse clock logic used for Margay!
void setup() {
	Serial.begin(38400); 
	pinMode(DATA_PIN, INPUT);  //Set pin modes for clock and data 
	pinMode(CLK_PIN, OUTPUT);
	#if defined(POWER_PIN);
		pinMode(POWER_PIN, OUTPUT);
		digitalWrite(POWER_PIN, LOW); //Turn on external power
		delay(5000); //Allow for charge 
	#endif
}

void loop() {
  Serial.print("Counts = "); 
  Serial.println(GetTicks());  //Get and print data
  ClearTicks(); //Clear data
  #if defined(POWER_PIN)
	digitalWrite(POWER_PIN, HIGH); //Turn off power
	delay(60000); //Wait a bit
	digitalWrite(POWER_PIN, LOW); //Turn on power
	delay(10);
  #endif
}

unsigned int GetTicks() 
{
	unsigned int Data = 0; //Number of pulses since last read
	digitalWrite(CLK_PIN, HIGH);  //Pulse clock pin high for 5ms to load new data
	delay(7);
  digitalWrite(CLK_PIN, LOW); 

	for(int i = 0; i < 16; i++) {
    digitalWrite(CLK_PIN, HIGH); 
		delayMicroseconds(500); //Wait to stabilize
		Data = (Data << 1) | digitalRead(DATA_PIN);
		// Serial.println(digitalRead(DATA_PIN));
    digitalWrite(CLK_PIN, LOW); 
		delayMicroseconds(500);
	}

	return Data;
}

void ClearTicks() 
{
	digitalWrite(CLK_PIN, HIGH);  //Pulse clock pin high for 10ms to clear data
	delay(20);
  	digitalWrite(CLK_PIN, LOW); 
}

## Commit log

2018-05-22 WIP simulations for control circuitry
2018-05-23 Added schematic for event counter with preliminary layout
    Schematic is essentially complete, very preliminary part placement done on board
    [EventCounter.brd, EventCounter.sch]
2018-05-23 Cleaned up schematic and added frame
    [EventCounter.sch]
2018-05-24 Completed initial routing, added silk screen info
    Board is functionally complete baring cleanup or modifications, added silk screen info to bottom layer
    [EventCounter.brd, EventCounter.sch]
2018-05-24 Changed passive values
    Changed the passive resistor divider values, need to verify with part availability
    [EventCounter.brd, EventCounter.sch]
2018-05-25 Changed resistor divider values for low power
    After checking part availability, changed values to more logical ones
    [EventCounter.brd, EventCounter.sch]
2018-06-05 Added BOM and decoupling cap
    Added BOM files and decoupling capacitor, cleaned up some silkscreen issues, ready for final review
    [EventCounter.brd, EventCounter.sch, EventCounter_BOM.csv]
2018-06-06 Added Gerbers, ready for first run
    Did cleanup and added reverse polarity symbol, generated gerbers, also updated gitignore to deal with LTSpice files
    [EventCounter.brd, EventCounter.sch]
2018-06-28 Added input signal conditioning, added test script
    Added input signal conditioning to fix metastability problem occurring due to excessive rise times due to pullup input
    [EventCounter.brd, EventCounter.sch]
2018-06-28 Updated part info, license and BOM
    [EventCounter.brd, EventCounter.sch, EventCounter_BOM.csv]
2018-07-10 Updated gerbers
    [EventCounter.brd]
2018-07-17 Added stencil DXF
    [EventCounter-bcream.dxf, EventCounter-tcream.dxf, EventCounter.dxf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]
2018-11-08 Initial layout of capacitor charge board
    Early layout of external capacitor charge board
    [SwitchedPowerAdapter.brd, SwitchedPowerAdapter.sch]
2018-11-27 Generated gerbers, updated part number on Switched Power
    [SwitchedPowerAdapter.brd, SwitchedPowerAdapter.sch]
2019-01-04 Const Power Adapter minor edits, generated gerbers
    Minor edits to silkscreen on Const Power Adapter and generated gerbers, submitted adapter board v0.0 to fab
    [SwitchedPowerAdapter.brd, SwitchedPowerAdapter.sch]
2019-04-08 Added testing data and updated TallyTest to support power switching
2019-04-08 Added board dimensions and generated PDFs
    [EventCounter.brd]
2019-04-18 Added initial developments for I2C variant
    Added first cut schematic for I2C variant, needs verification and decent cleanup
    [EventCounter_I2C.brd, EventCounter_I2C.sch]
2019-04-19 Initial layout for I2C variant
    First cut layout for I2C variant, passes DRC, still needs verification
    [EventCounter_I2C.brd, EventCounter_I2C.sch]
2019-04-20 Minor edits, sent to fab for v1.0 (I2C model)
    Cleaned up layout, added pullup reset resistor, generated gerbers, sent v1.0 to fab
    [EventCounter_I2C.brd, EventCounter_I2C.sch]
2019-04-30 Updated values/digikey info
    Updated the part
    [EventCounter_I2C.brd, EventCounter_I2C.sch]
2019-05-15 Updated firmware, minor design update
    Improved firmware capabilities, added minor design updates to schematic, routing and feature decision still required
    [EventCounter_I2C.brd, EventCounter_I2C.sch]
2019-05-15 Routing and design update for v1.1
    Cleanup/verification required before sending to fab
    [EventCounter_I2C.brd, EventCounter_I2C.sch]
2019-05-16 Minor cleanup, generated gerbers, sent v1.1 to fab
    Minor cleanup and rearranging silkscreen names, changed jumper configuration
    [EventCounter_I2C.brd, EventCounter_I2C.sch]
2019-05-27 Added support for v1.2 I2C board in firmware
    Added support for voltage reading on the v1.2 I2C board, still need to rename/organize firmware
2019-05-29 Updated voltage read in firmware
    Added voltage read on startup, so you can read minimum voltage after cycle is completed
2019-06-06 Minor value updates
    [EventCounter_I2C.brd, EventCounter_I2C.sch]
2019-06-13 Updated part values
    Switched values of `R10` and `R11`, values were erroneously switched which resulted in the capacitor being connected to the ADC input during sleep/off state, causing significant power draw
    [EventCounter_I2C.brd, EventCounter_I2C.sch]
2019-06-28 Attempted gitignore tracking fix
    [EventCounter_BOM.csv]
2019-06-28 Re-added CSVs, reorganized folder structure
    [EventCounter-bcream.dxf, EventCounter-tcream.dxf, EventCounter.brd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]
2019-06-28 Updated readme, added switched cap support in firmware
    Added support for switched capacitor and changed naming of `reset` and `clear` to match that of software library
    [Tally_Firmware_1v1.ino]
2020-04-30 Stencil flat surface for solder-paste application
    [StencilMount_Tally_I2C.SLDPRT, StencilMount_Tally_I2C.STL]

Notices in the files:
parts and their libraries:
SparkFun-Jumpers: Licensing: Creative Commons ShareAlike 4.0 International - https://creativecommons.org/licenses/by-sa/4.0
